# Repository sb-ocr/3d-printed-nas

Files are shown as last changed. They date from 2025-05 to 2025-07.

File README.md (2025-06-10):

# 3D Printed NAS

Watch the build video ↓

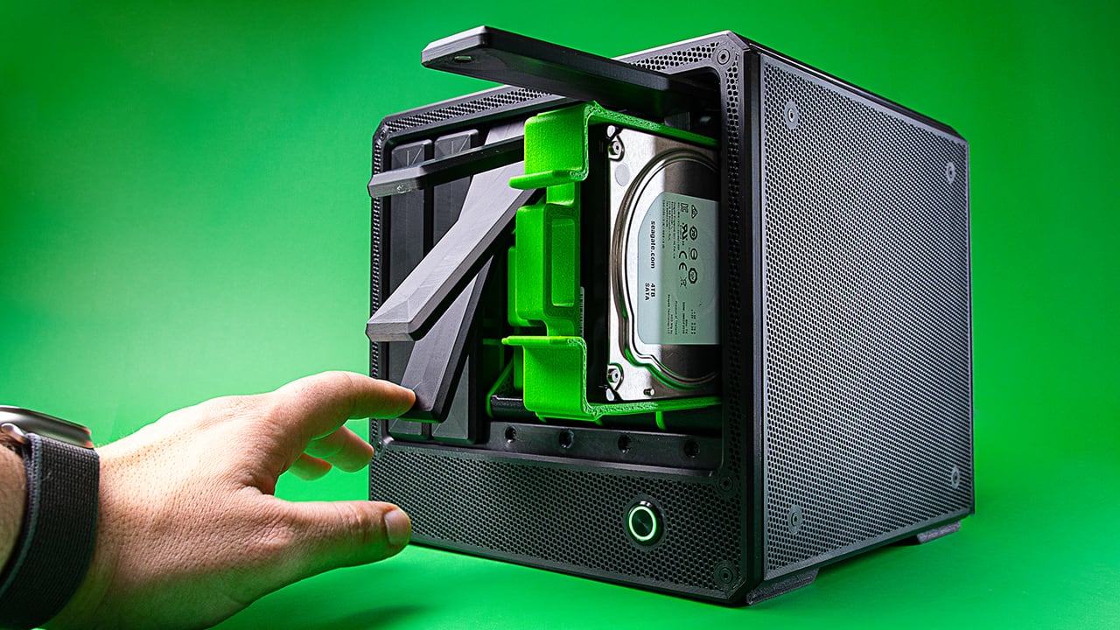
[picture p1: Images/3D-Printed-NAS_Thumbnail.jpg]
[](https://youtu.be/NXIu-B52WPU)

I was juggling too many small SSDs for backups, so I set out to build something more permanent.
In this video, I walk you through the design and build of a custom NAS powered by the ZimaBoard — complete with a custom power adapter PCB and tool less drive trays.

Build instructions → [Instructables](https://www.instructables.com/3D-Printed-Home-Server-6-Bay-ZimaBoard-NAS/)

[][cc-by-nc-sa]

[][cc-by-nc-sa]

[cc-by-nc-sa]: http://creativecommons.org/licenses/by-nc-sa/4.0/
[cc-by-nc-sa-image]: https://licensebuttons.net/l/by-nc-sa/4.0/88x31.png
[cc-by-nc-sa-shield]: https://img.shields.io/badge/License-CC%20BY--NC--SA%204.0-lightgrey.svg

<sub>Affiliate links may be included in this repo. I may receive a small commission at no additional cost to you.</sub>

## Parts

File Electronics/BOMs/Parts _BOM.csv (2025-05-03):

Qty | Description | Link
1 | ZimaBoard 832 Single Board Server | https://geni.us/uwBCZ
2 | Noctua NF-A4x10 FLX 3-Pin 12V (40x10mm) | https://geni.us/Fkr3L
2 | Noctua NF-R8 redux-1800 3-Pin 12V (80mm) | https://geni.us/5GhNKWv
1 | Momentary Black Push Button 12V LED Ring Head (16mm hole) | https://geni.us/luLH
1 | SATA PCIE Expansion Card (4 Ports) | https://geni.us/9vRfBY
1 | 90 Degree PCI Extension Cable (15cm) | https://geni.us/D940HF5
2 | Molex IDE Male to 3 x 15 Pin SATA Power Supply | https://geni.us/eeVQD
1 | Power Socket Inlet Module | https://geni.us/WkVR7
6 | SATA 22 Pin (7+15) Male to 22 pin Female Extender | https://geni.us/wC48Yf
1 | Multiple Output 5V(10A) 12V(12A) Power Supply | N/A

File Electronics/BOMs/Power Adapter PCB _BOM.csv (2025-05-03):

Qty | Value | Device | Package | Parts | Digikey | Description
1 |  | 691216510003S | 691216510003S | PSU_IN | 732-691216510003S-ND | "3 Position Wire to Board Terminal Block Horizontal with Board 0.200"" (5.08mm) Through Hole"
1 |  | 6130XX11021_61300411021 | 61300411021 | POWER_SW | 732-5337-ND | "Connector Header Through Hole 4 position 0.100"" (2.54mm)"
1 |  | 6130XX21121_61300621121 | 61300621121 | ZIMA_PWR | 732-5295-ND | "Connector Header Through Hole 6 position 0.100"" (2.54mm)"
1 |  | 6130XX21121_61301421121 | 61301421121 | ZIMA_IO | 732-5298-ND | "Connector Header Through Hole 14 position 0.100"" (2.54mm)"
4 | 0.1uF | C-US_CHIP-1206(3216-METRIC) | CAPC3216X135 | "C1 | C2 | C3 | C4" | 399-C1206C104K5RACTUCT-ND | 0.1 µF ±10% 50V Ceramic Capacitor X7R 1206 (3216 Metric)
4 | 10k | R-US_CHIP-1206(3216-METRIC) | RESC3216X70 | "R2 | R4 | R1 | R3" | 311-10.0KFRCT-ND | "10 kOhms ±1% 0.25W | 1/4W Chip Resistor 1206 (3216 Metric)"
4 | 10uF | WCAP-ASLI_4X5.5 | WCAP-ASLI_4X5.5(DXL) | "C5 | C6 | C7 | C8" | 732-8451-1-ND | 10 µF 50 V Aluminum Electrolytic Capacitors Radial
2 | 16V/10A | PPTC_PTH | PTH | "F1 | F2" | PTR016V1000-BK-ND | Polymeric PTC Resettable Fuse 16V 10 A Ih Through Hole
4 |  | 22-23-2031 | 22-23-2031 | "X1 | X2 | X3 | X4" | WM4201-ND | "Molex Connector Header Through Hole 3 position 0.100"" (2.54mm)"
2 |  | 350211-1350211-1_TYC | 350211-1_TYC | "DRIVES_PWR1 | DRIVES_PWR2" | A1212-ND | "Molex Connector Header Through Hole 4 position 0.200"" (5.08mm)"
2 | 40A/30V/10mΩ | MOSFET_PCH-MCU20P10 | TO-252/DPAK | "Q2 | Q4" | 3141-G40P03KCT-ND | P-Channel 30 V 40A (Tc) 78W (Tc) Surface Mount TO-252
2 | MMBT2222AL | NPN_MMBT2222ALT1G_SOT23-BEC | SOT95P237X112-3N | "Q1 | Q3" | MMBT2222ALT1GOSCT-ND | Bipolar (BJT) Transistor NPN 40 V 600 mA
1 |  |  |  |  | 732-61300621821-ND | "6 Position Receptacle Connector 0.100"" (2.54mm) "
1 |  |  |  |  | 2057-RS2-14-G-ND | "14 Position Receptacle Connector 0.100"" (2.54mm)"

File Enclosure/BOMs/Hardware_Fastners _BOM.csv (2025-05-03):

Qty | Description | Link
52 | M3 x 10mm-12mm Hexagon Socket Countersunk Head Screw | https://geni.us/bYhU
20 | M3 x 10mm Hexagon Socket Head Cap Screw | https://geni.us/5N61va
72 | M3 Heat Set Inserts | https://geni.us/PdB8mWk
6 | M6 Fully Threaded Rods | https://geni.us/T6Quy
12 | M6 Hex Nuts | https://geni.us/BPGwNiY
29 | M6 Nylon Washers (1.2 mm Thickness) | https://geni.us/38l20a

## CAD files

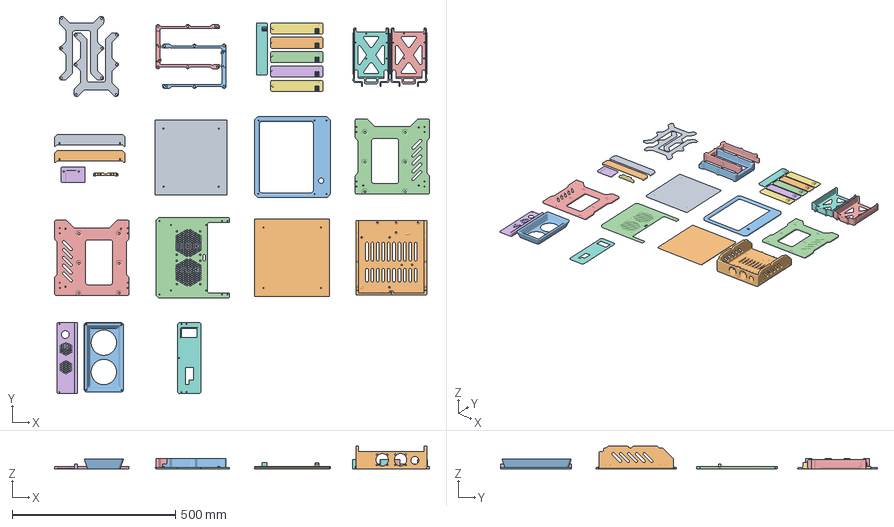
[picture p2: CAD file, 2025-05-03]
Enclosure/CAD/3MF/3D Printed NAS _Bambu Plates.3mf
1149.1 x 1154.2 x 70.3 mm
Base
Back fan housing
Back plate
Caddy
Front grill
Cover x 6
Caddy 1
Slot x 2
Face plate
Side L
Side plate
PCIe support
Back panel IO
Side cover
Top cover

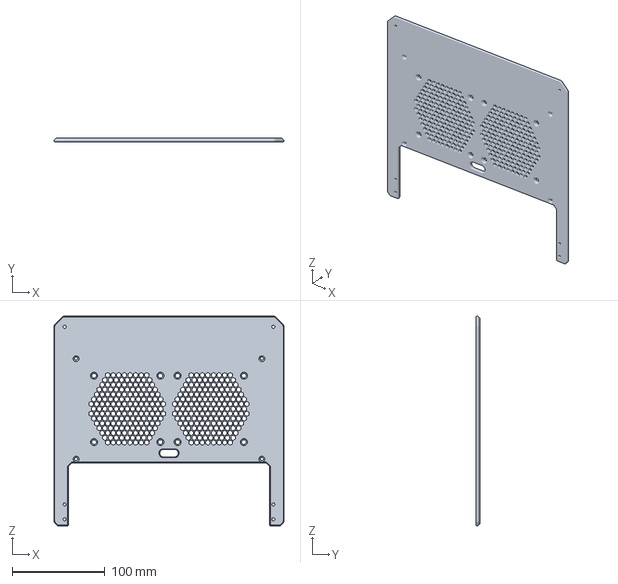
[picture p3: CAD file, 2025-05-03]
Enclosure/CAD/3MF/Covers/Back plate.3mf
247.8 x 4.00 x 226.1 mm

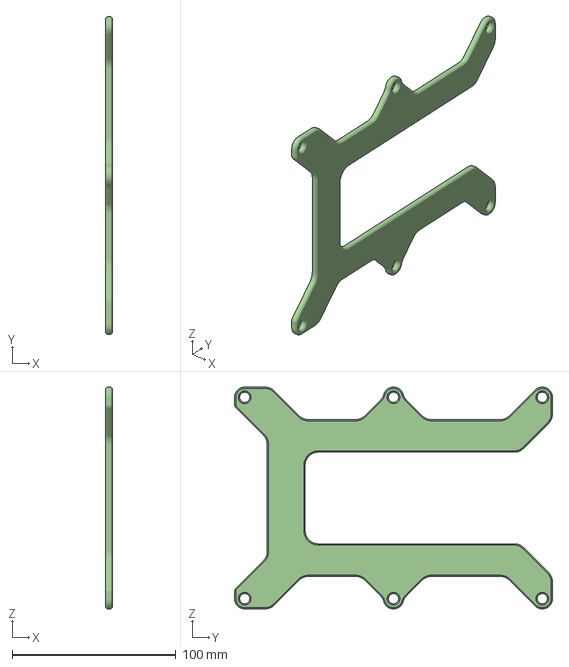
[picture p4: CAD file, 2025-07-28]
Enclosure/CAD/3MF/Drives/Separator.3mf
4.00 x 194.5 x 135.7 mm

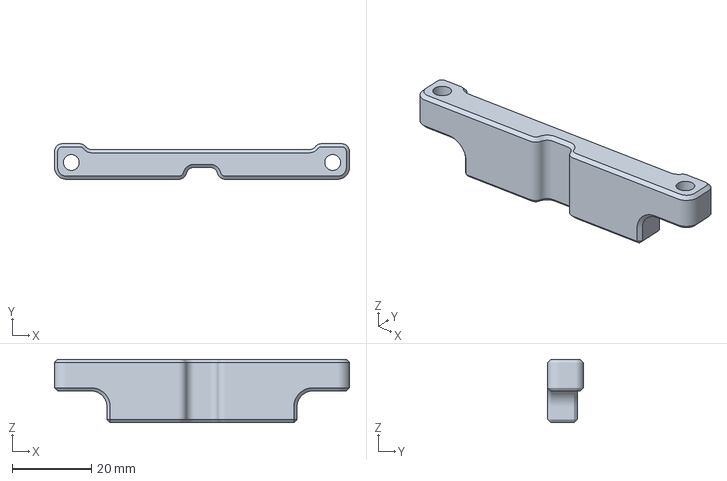
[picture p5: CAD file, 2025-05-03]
Enclosure/CAD/3MF/Structure/Zima support.3mf
74.5 x 9.00 x 16.0 mm

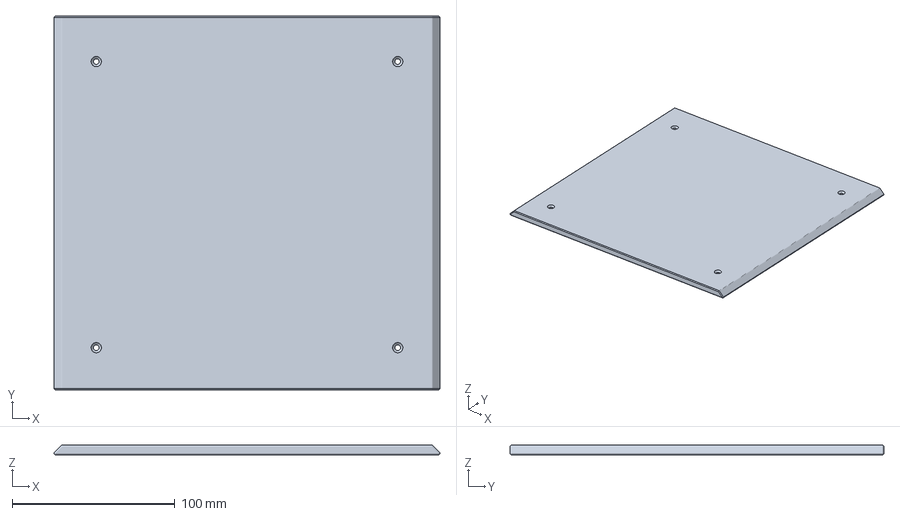
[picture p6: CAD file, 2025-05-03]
Enclosure/CAD/3MF/Covers/Top cover.3mf
237.4 x 230.0 x 6.00 mm

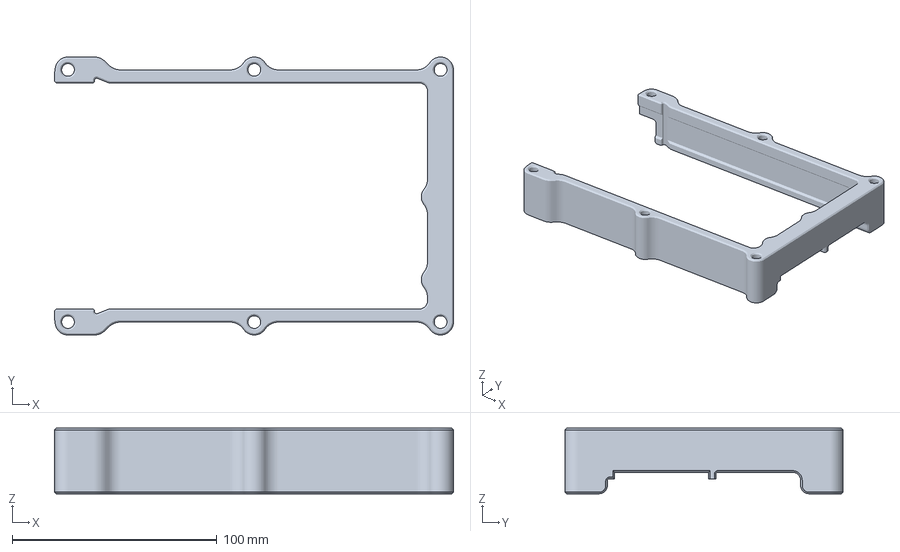
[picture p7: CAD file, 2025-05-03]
Enclosure/CAD/3MF/Drives/Slot.3mf
194.9 x 135.8 x 32.0 mm

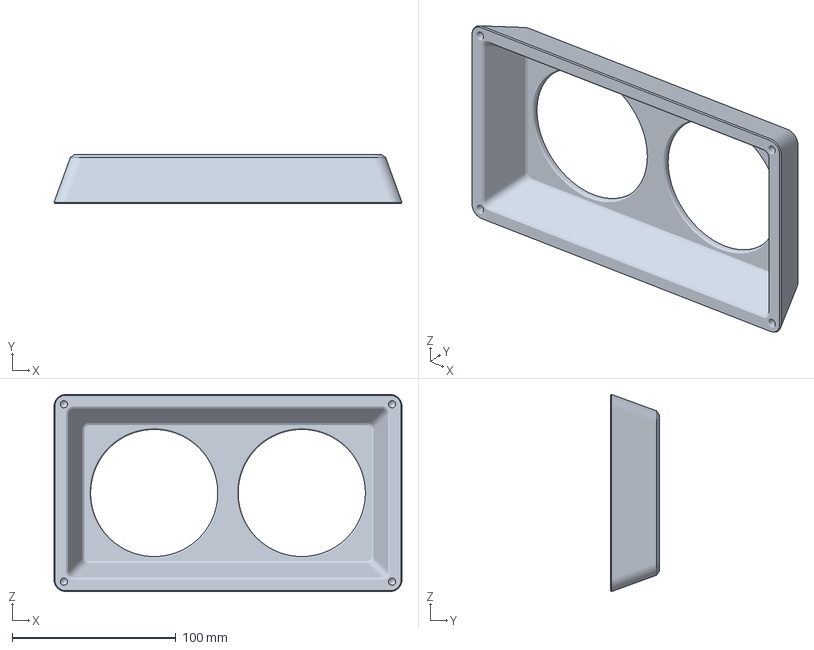
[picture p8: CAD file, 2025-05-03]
Enclosure/CAD/3MF/Structure/Back fan housing.3mf
212.2 x 30.0 x 120.2 mm

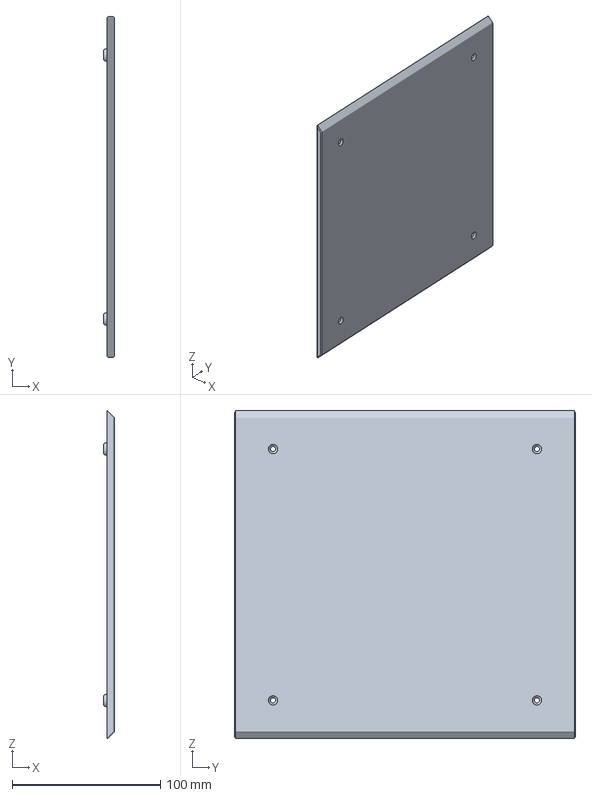
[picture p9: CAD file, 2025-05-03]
Enclosure/CAD/3MF/Covers/Side cover.3mf
7.30 x 230.0 x 221.3 mm

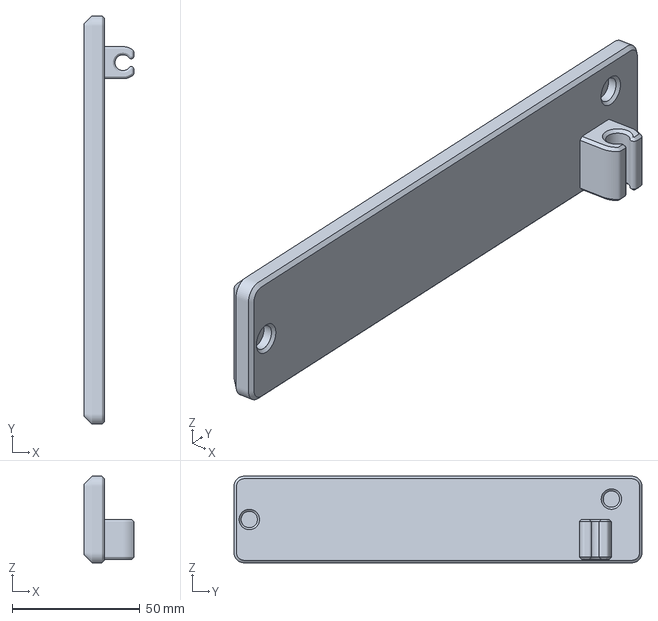
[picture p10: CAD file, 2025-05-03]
Enclosure/CAD/3MF/Drives/Cover.3mf
19.4 x 160.0 x 34.0 mm

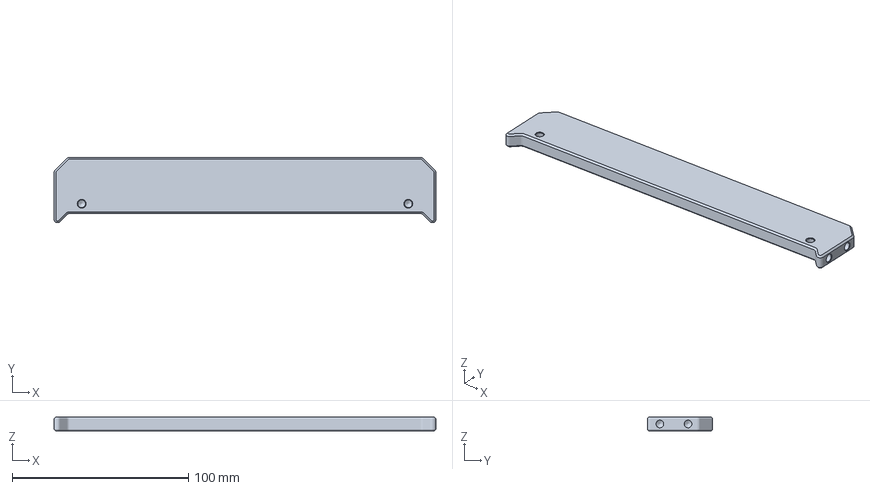
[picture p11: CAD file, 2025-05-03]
Enclosure/CAD/3MF/Structure/Brace.3mf
216.8 x 37.2 x 8.00 mm

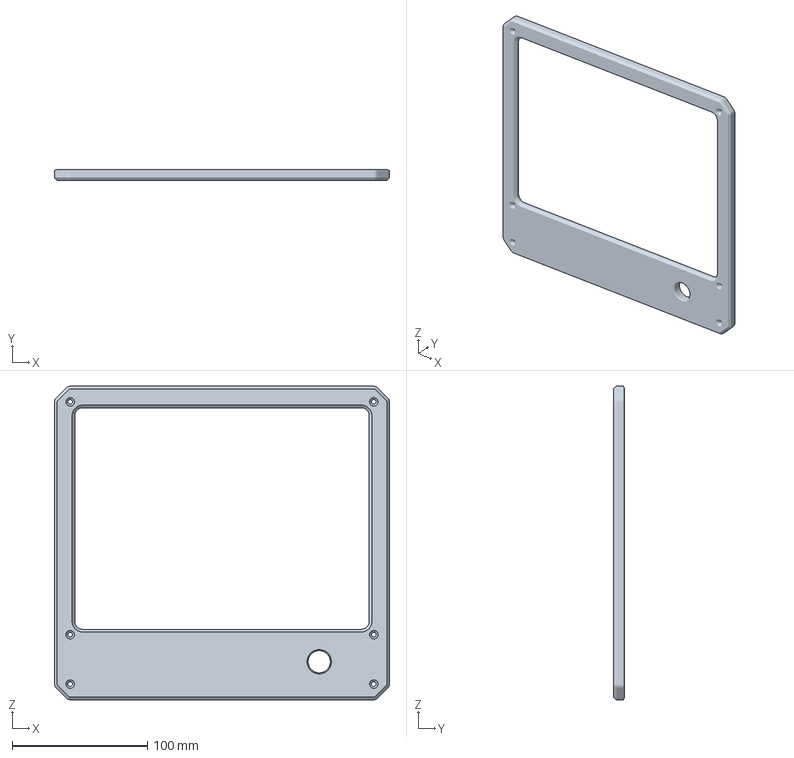
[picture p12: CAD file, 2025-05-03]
Enclosure/CAD/3MF/Covers/Face plate.3mf
248.0 x 8.00 x 232.2 mm

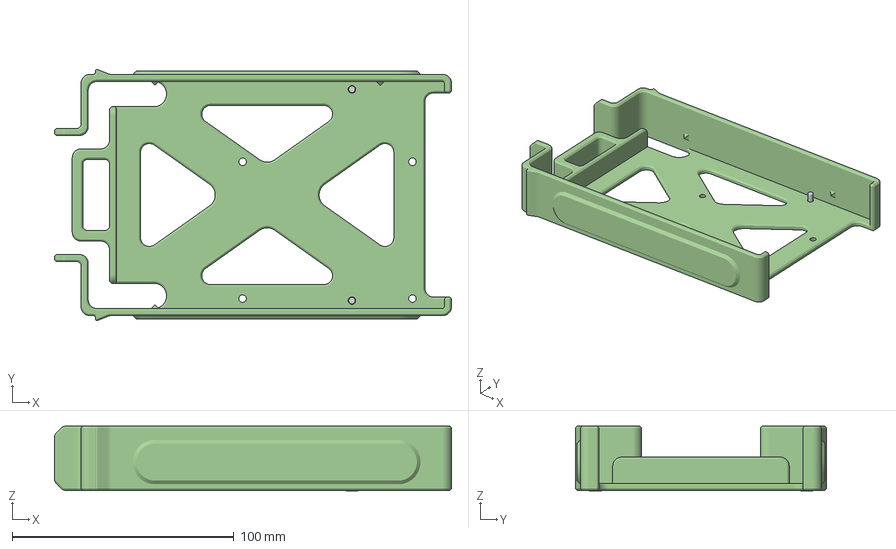
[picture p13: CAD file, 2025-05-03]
Enclosure/CAD/3MF/Drives/Caddy.3mf
179.0 x 113.2 x 29.2 mm
Caddy

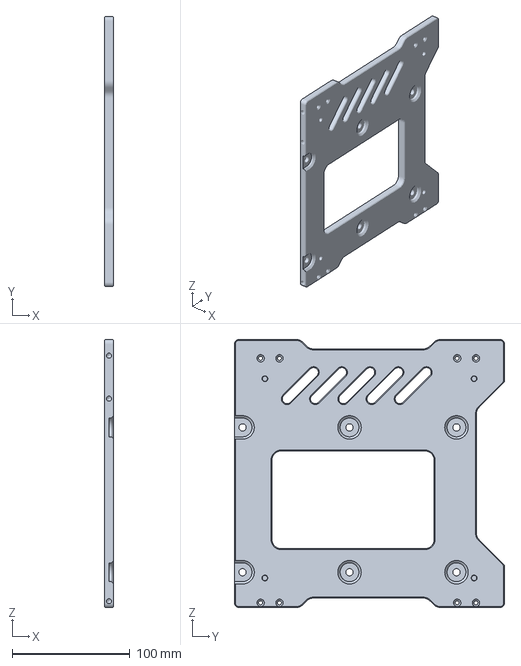
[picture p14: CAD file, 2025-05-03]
Enclosure/CAD/3MF/Structure/Side plate R.3mf
8.00 x 230.0 x 228.0 mm

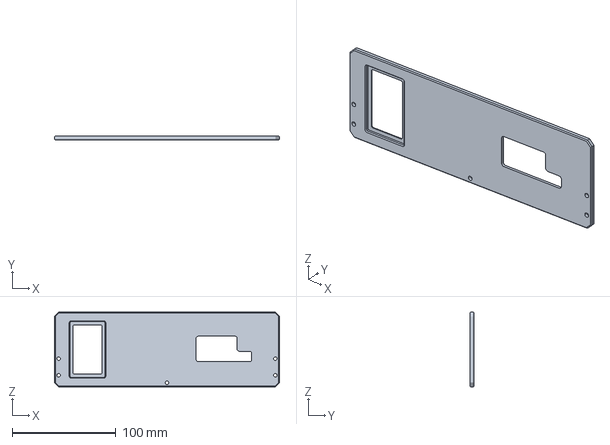
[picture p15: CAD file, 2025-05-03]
Enclosure/CAD/3MF/Covers/Back IO.3mf
216.8 x 4.00 x 72.0 mm

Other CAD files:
Enclosure/CAD/3MF/Structure/Base.3mf
Enclosure/CAD/3MF/Structure/Side plate L.3mf
Enclosure/CAD/3MF/Structure/PCIe card support.3mf
Enclosure/CAD/3MF/Structure/Front grill.3mf
Enclosure/CAD/STL/Covers/Back IO.stl
Enclosure/CAD/STL/Covers/Back plate.stl
Enclosure/CAD/STL/Covers/Face plate.stl
Enclosure/CAD/STL/Covers/Side cover.stl
Enclosure/CAD/STL/Covers/Top cover.stl
Enclosure/CAD/STL/Drives/Caddy.stl
Enclosure/CAD/STL/Drives/Cover.stl
Enclosure/CAD/STL/Drives/Separator.stl
Enclosure/CAD/STL/Drives/Slot.stl
Enclosure/CAD/STL/Structure/Back fan housing.stl
Enclosure/CAD/STL/Structure/Base.stl
Enclosure/CAD/STL/Structure/Brace.stl
Enclosure/CAD/STL/Structure/Front grill.stl
Enclosure/CAD/STL/Structure/PCIe card support.stl
Enclosure/CAD/STL/Structure/Side plate L.stl
Enclosure/CAD/STL/Structure/Side plate R.stl
Enclosure/CAD/STL/Structure/Zima support.stl

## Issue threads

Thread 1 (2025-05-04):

Single version for 5.25'' bays

ofernandolopes, 2025-05-04:
@sb-ocr, it would be interesting to have an individual slot version for 5.25'' bays to take advantage of old cases and use ATX boards. For example, I have a tower case that could hold 9 disks in the 5.25'' bays.

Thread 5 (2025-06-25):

Version wo/ compute

caitlynrw, 2025-06-25:
Hi there, love the design. Just wondering if you could make a variant that doesn't have the Zimaboard stuff, so I can use it as a JBOD? Maybe with space for a small ATX PSU or something similar

sb-ocr, 2025-07-28:
Thanks, I don't have plans to make other variants for now but you're most welcome to modify the "Base" and "Back IO Plate" to do that. I believe there is enough space for that.

Closed 2025-07-28.

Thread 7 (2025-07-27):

Missing STL/3MF file: Drives > 'separator'

MrStaf, 2025-07-27:
Hi! Thank you for this excellent project. I'm planning to print it, but I've noticed that the 'separator' file in the Drives folder appears to be missing from both the STL and 3MF formats.
Since I don't have access to Fusion 360 to export it myself, would it be possible for you to add this file to the repository?
I'd really appreciate your help with this!
Thanks in advance.

sb-ocr, 2025-07-28:
Hi, Thanks for letting me know. It's added to the CAD folder.

Closed 2025-07-28.

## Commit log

2025-05-03 Initial upload
    [3D Printed NAS _Bambu Plates.3mf, Back IO.3mf, Back IO.stl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]
2025-07-28 Separator STL + 3MF
    [Separator.3mf, Separator.stl]

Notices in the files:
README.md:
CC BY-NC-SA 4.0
